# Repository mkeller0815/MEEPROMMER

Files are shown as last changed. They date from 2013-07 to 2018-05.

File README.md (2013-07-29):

MEEPROMMER
==========

(E)EPROM programmer based on Arduino hardware

The MEEPROMMER is a combination of hardware and software that lets you read and write 
data from (and to) 28Cxxx EEPROMS. Maybe later there will be enhancements to use it
also for 27Cxxx EPROMS. 

At the moment we have an working prototype on a PCB that uses an Arduino Nano and an 
Arduino-shield that can directly plugged to an Arduino Uno. 

The Arduino firmware provides a serial interface with simple commands to transfer data 
between a host computer and an eeprom.

For the host computer a Java based GUI application is available that uses the RXTX 
library to interface the programmer.

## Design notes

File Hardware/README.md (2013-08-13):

this folder contain the hardware related files

The PCB is available at: https://www.tindie.com/products/UnaClocker/28cxxx-eeprom-programmer-shield-for-arduino/

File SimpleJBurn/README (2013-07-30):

SimpleJBurn
###########

SimpleJBurn is a java application that is used to write data to an EEPROM or
read data from an EEPROM. 

The current version has the following features:

- Load an ROM image from disk (up to 32k)
- Read data from EEPROM
- Save EEPROM data to disk
- Burn image data to EEPROM 
- set an offset for burning data
- compare image data and EEPROM data
- clear EEPROM to 0x00 bytes

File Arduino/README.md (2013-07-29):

This folder contains the Arduino related files for the
firmware

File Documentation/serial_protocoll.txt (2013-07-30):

################################################################################
#
# Atmega328 based EEPROM 28C64,28C256 programmer
# serial protocol description
#
# $Date: 2013/04/12 10:55:16 $
# $Author: mario $
# $Revision: 1.4 $
#
# $Id: serial_protocoll.txt,v 1.4 2013/04/12 10:55:16 mario Exp mario $
# $Source: /Users/mario/Projekte/HomeBrew6502/Hardware/EEPROM\040Programmer/serial_protocoll.txt,v $
#  
################################################################################

Description
###########

This document describes the serial protocol that is used to talk
to the programmer. 

The programmer supports binary data as well as the Intel HEX format
version I08HEX. (support for datatype "00" and "01").
If the I08HEX dataset is page-aligned with a maximum of 64 bytes per 
row, the programmer automatically uses the fast page-write mode.

For the binary modei, page-write can be selected directly by the 
write command.

The software uses the "Data polling" mode (DB7) of the AT and ST 
models of the 28Cxxx EEPROMS to determine the end of a write cycle.

Communication
#############

The baud rate is fixed at 9600,8,N,1. This should be enough because
it provides about 1k of data to be written in one second by using 
binary write in page mode.

The programmer waits on its serial port for a command. Any command 
that is send to the programmer will be parsed and executed. At the
end a return code of 2 bytes will be send back (at least) with 
information about the success of the command execution. 

A command has to be terminated by either LF (0x0A) or CR/LF (0x0D 0x0A)
Parameters are separated by ","

Example: "bw,0f00,00ff" (command binary write at 0x0f00, 255 bytes)
         After sending the command you can check for any error code.
	 If no code is send by the programmer you can start transmitting
	 the data.

If a command was given that reads data from the EEPROM, the return 
code is send after the data has been sent. To separate the return 
code from the "data", you have to count the number of data bytes. 
This should be easy, cause for all write and read commands a 
implicit or explicit length is needed in the command parameters.

Adresses and length values are always given as hex numbers that
are always 4 byte hex values for a 16bit address 0000 to 7fff  
without the '0x' prefix. Any number bigger the 7fff will cause
an error because you should never have a address beyond 0x7fff.

Commands and parameters are always given as ASCII text, 

Commands
########

* bw	- binary write byte mode
* pw	- binary write page mode
* br	- binary read 
* hw	- intel hex write
* Hw	- intel hex write (page mode)
* hr	- intel hex read
* ??	- print help
* ve	* print version

Error codes
###########

* 00	- OK
* 01	- unknown command
* 02	- data length mismatch
* 03    - timeout waiting for data
* 04	- page align error (page write mode)
* 05    - too many bytes (page write mode)
* 06	- wrong checksum
* 07	- datatype not implemented (intel hex format)
* 08    - wrong data line format (intel hex format)
* 09	- wrong hex value in address or byte value

bw command:
-----------

  syntax:	bw,address,length

  parameter:	address :	16 bit value (0000 to 7fff) repesenting the 
				start address of the bytes to write
		length  :	16 bit value (0000 to 7fff) with number of 
				bytes to be written 

  description:	binary write "length" bytes beginning with "address". After the
		command is sent the programmer responses only in case of an 
		error with a return code. After sending the command the number 
		of databytes (binary, not as hex value) have to be send to the 
		programmer. If the number is not reached, the programmer waits 
		5 seconds after recieving the last byte until an error code is 
		returned (error 02 - data length mismatch). If too many bytes 
		are send, the programmer will stop writing the received bytes 
		to the eeprom after the "length" number of bytes are reached, 
		but the next byte that is send after that will be interpreted 
		as new command, causing either an error (01 - unknown command) 
		or unwanted behavior, because the byte is recognized as command
		If the write cycle needs some time to finish, you may have to 
		insert some breaks of about 50 ms after each 100 bytes. 
		After the bytes are successful written, the return code 
		"00" (OK) is returned, then the programmer waits for the next 
		command. 

pw command:
-----------

  syntax:	pw,address,length

  parameter:    address :       16 bit value (0000 to 7fff) repesenting the 
				start address of the bytes to write.
				the address has to be page aligned. 
				0000, 0040, 0080, 00a0, 0100, ... , etc.
                length  :       16 bit value (0000 to 0040) with number of 
				bytes to be written (maximum 64 byte)

  description:	binary write data in "page mode". This mode is much faster 
		then writing single bytes, but has some requirements. First is 
		that the address has to be page aligned. The next is that only 
		64 bytes can be written in one step. The bytes are read into 
		an internal buffer befor writing. The rest is done in the same 
		way like writing binary bytes. After the command is sent, the 
		programmer responses with a return value only in case of an 
		error. You can start sending the bytes directly after sending 
		the command string. In case of a misalignment of the address 
		the return value "04" (page align error) is returned. If the 
		length parameter is bigger then 0x0040 (64 bytes) the error 
		"05" (too many bytes) is returned. In case of any error, do 
		not start sending databytes, as they are interpreted as new 
		command, causing errors or unwanted behavior.  

br command:
-----------

  syntax:	br,address,length

  parameter:    address :       16 bit value (0000 to 7fff) repesenting the 
				start address of the bytes to read
                length  :       16 bit value (0000 to 7fff) with number of 
				bytes to be read

  description:	binary read data, beginning at the given address. The "length" 
		number of bytes are read from the eeprom and send to the serial
		connection as single byte values (not hex values). After the 
		"length" number of bytes are sent, the additional return value 
		"00" (OK) is sent. Be aware that these two byte do not belong 
		to the data from the eeprom, so take care for the number of 
		bytes that you expect from the read command.  

hw command:	
-----------

  syntax:	hw

  parameter:	none

  description:	start intel hex format write. The current firmware only supports
		I09HEX format, implementing the "00" data record and the "01" 
		end of file record types. the maximum number of bytes per data 
		line is 256 (third field in record line 0x00 to 0xff ). The 
		line has to end with either LF or CR/LF. A complete line is read
		into an internal buffer and then is parsed and written to the 
		EEPROM. If the address is page aligned an there are not more 
		then 64 bytes in the line the programmer automatically uses the
		faster page write mode.  If the checksum is not correct, an 
		error is returned (06) and the data line will not be written.
		Errors are also returned if 
		* a wrong record type is used (07)
		* the format of the dataline is not correct (08)
		* mistyped hex values are found in the line (09)
		* the line is not completed and a timeout occures (03)
		After the line is written, the return value "00" is send to 
		indicate that the next line can be written. The last line to 
		send is a "01" record line (end of file record) to end the hex 
		write mode.

hr command:
-----------

  syntax:	hr,address,length,bbl

  parameter:    address :       16 bit value (0000 to 7fff) repesenting the 
				start address of the bytes to read
                length  :       16 bit value (0000 to 7fff) with number of 
				bytes to be read
		bbl	:	8 bit value (00 to ff) with the number 
				of bytes per line

  description:  this mode works like the binary read mode, except, that the 
		data is transmitted as intel hex format. Each line contains 
		the number of data bytes specified in the "bbl" parameter 
		(max. 255) also the checksum is provided at the end of the line.
		Lines are separated by "LF" the last line that is send is a "01"
		(end of file record) that indicated the end of the data 
		transmission. After the last line is send, the "00" return value
		is returned showing that the next command can be executed.  

?? command:
-----------

  syntax:	??

  parameter:	none

  description:	prints out the help text to the serial connection

ve command:
-----------

  syntax:	ve

  parameter:	none

  description:	prints out the version information of the current firmware
		The version string contains a version number as well as the 
		commands that are supported at the moment:
		like:  "MEEPROMER V0.91 2013-04-13; CMD:bw,br,pw,ve,??"

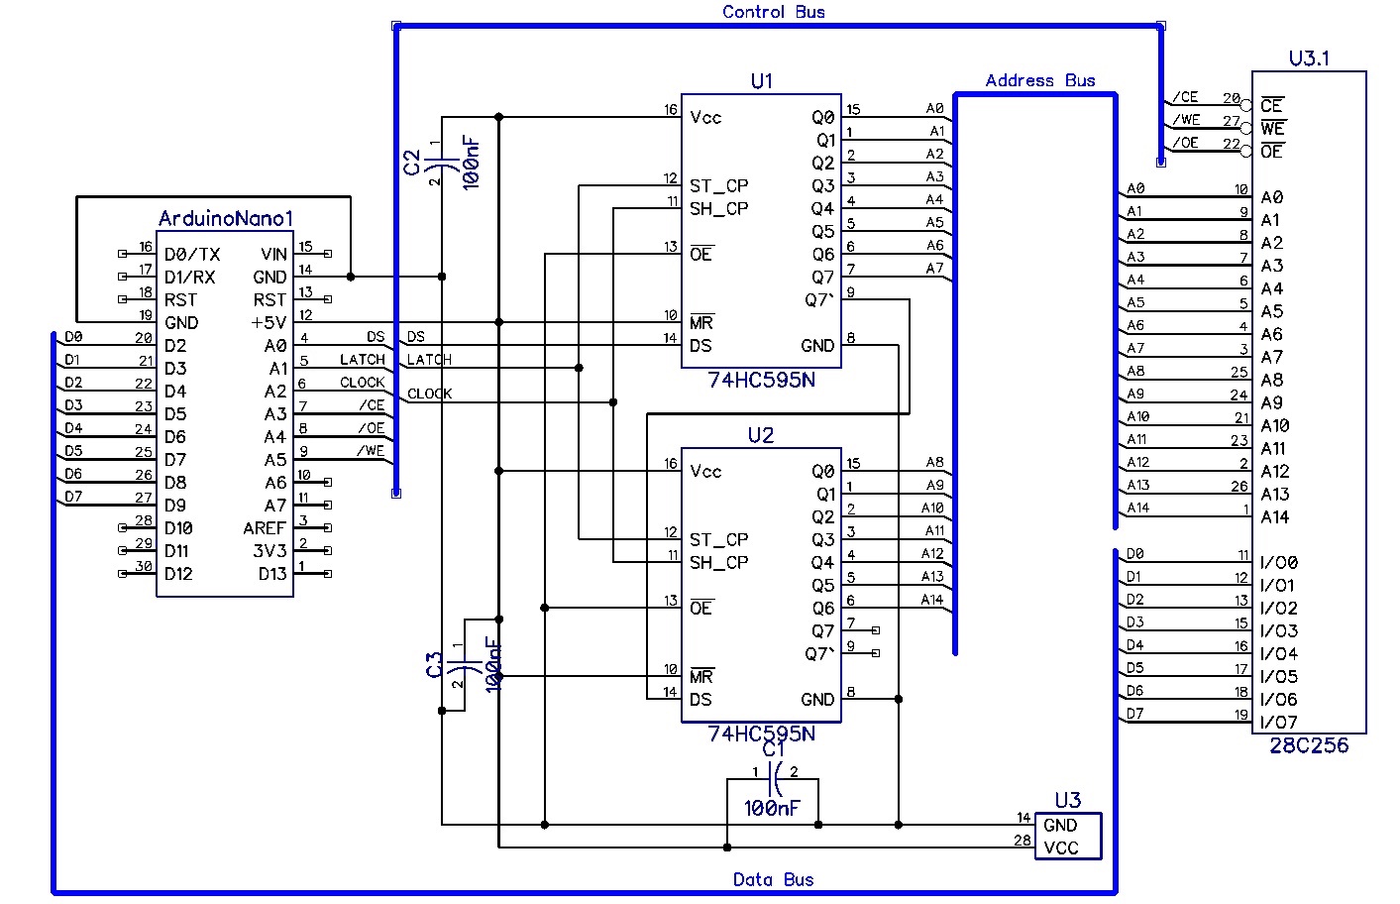
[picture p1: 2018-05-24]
Hardware/Prototype_schema.jpg

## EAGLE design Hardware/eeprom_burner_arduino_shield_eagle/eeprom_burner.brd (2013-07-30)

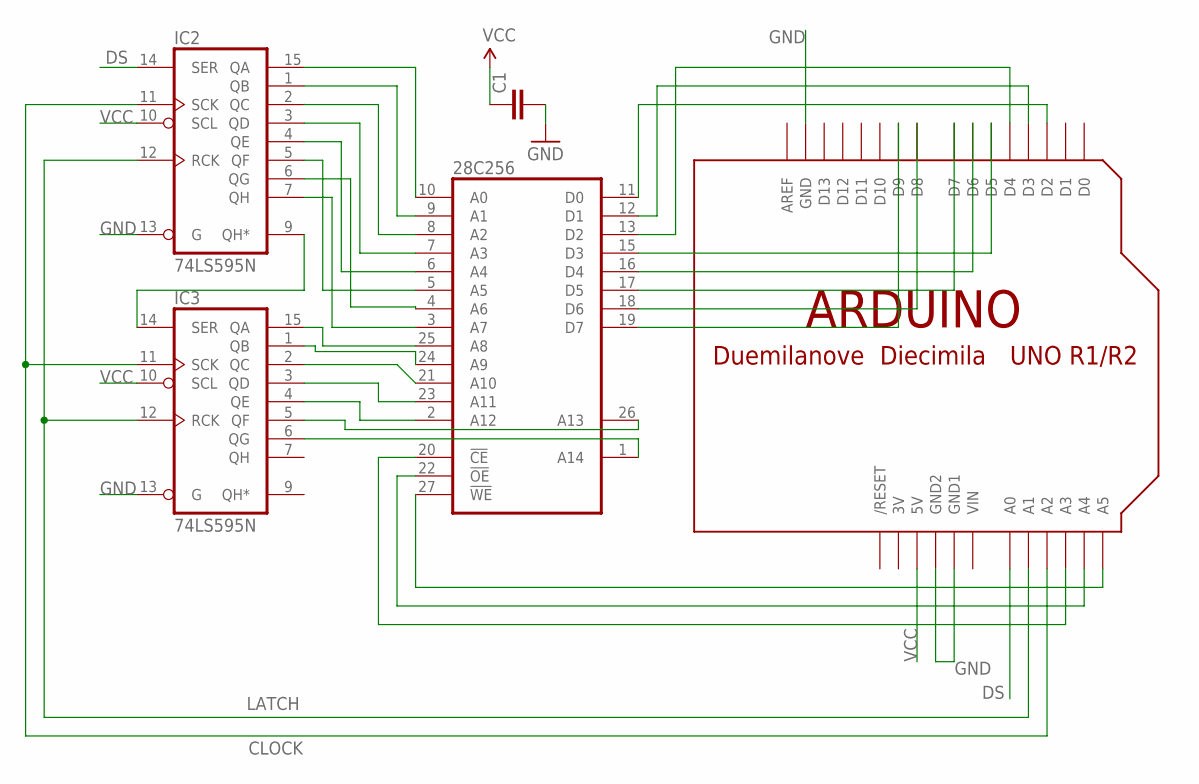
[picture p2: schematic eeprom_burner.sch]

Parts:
28C256: 2864; DIL28
C1: CAPPTH; CAP-PTH-SMALL
IC2, IC3: 74LS595N; DIL16
U$1: ARDUINOUNO; ARDUINO

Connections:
3V: U$1.3V
CLOCK: IC2.11 (SCK), IC3.11 (SCK), U$1.A2
DS: IC2.14 (SER), U$1.A0
GND: 28C256.14 (GND), C1.2, IC2.8 (GND), IC2.13 (G), IC3.8 (GND), IC3.13 (G), U$1.GND, U$1.GND1, U$1.GND2
LATCH: IC2.12 (RCK), IC3.12 (RCK), U$1.A1
unnamed: 28C256.27 (!WE), U$1.A5
unnamed: 28C256.22 (!OE), U$1.A4
unnamed: 28C256.20 (!CE), U$1.A3
unnamed: 28C256.11 (D0), U$1.D2
unnamed: 28C256.12 (D1), U$1.D3
unnamed: 28C256.13 (D2), U$1.D4
unnamed: 28C256.15 (D3), U$1.D5
unnamed: 28C256.16 (D4), U$1.D6
unnamed: 28C256.17 (D5), U$1.D7
unnamed: 28C256.18 (D6), U$1.D8
unnamed: 28C256.19 (D7), U$1.D9
unnamed: 28C256.10 (A0), IC2.15 (QA)
unnamed: 28C256.9 (A1), IC2.1 (QB)
unnamed: 28C256.8 (A2), IC2.2 (QC)
unnamed: 28C256.7 (A3), IC2.3 (QD)
unnamed: 28C256.6 (A4), IC2.4 (QE)
unnamed: 28C256.5 (A5), IC2.5 (QF)
unnamed: 28C256.4 (A6), IC2.6 (QG)
unnamed: 28C256.3 (A7), IC2.7 (QH)
unnamed: IC2.9 (QH*), IC3.14 (SER)
unnamed: 28C256.25 (A8), IC3.15 (QA)
unnamed: 28C256.24 (A9), IC3.1 (QB)
unnamed: 28C256.21 (A10), IC3.2 (QC)
unnamed: 28C256.23 (A11), IC3.3 (QD)
unnamed: 28C256.2 (A12), IC3.4 (QE)
unnamed: 28C256.26 (A13), IC3.5 (QF)
unnamed: 28C256.1 (A14), IC3.6 (QG)
VCC: 28C256.28 (VCC), C1.1, IC2.10 (SCL), IC2.16 (VCC), IC3.10 (SCL), IC3.16 (VCC), U$1.5V
VIN: U$1.VIN

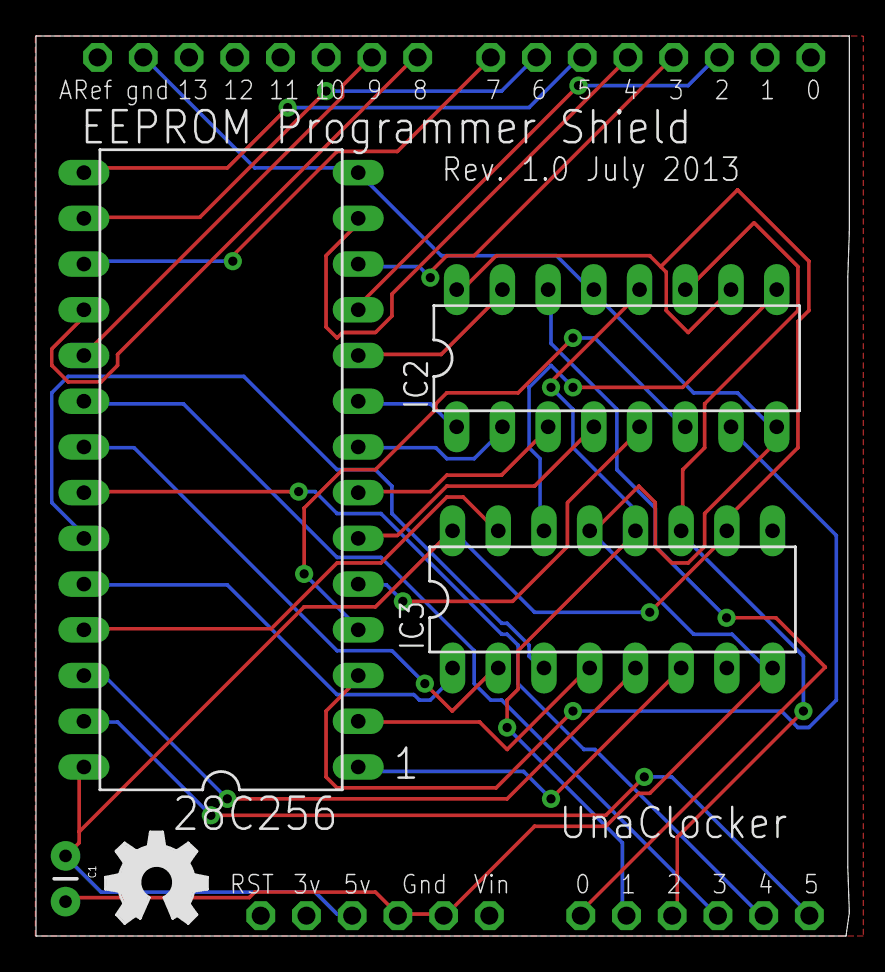
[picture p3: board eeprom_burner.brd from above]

Board: 2 copper layers, 45.2 x 50.0 mm, 7 parts (1 on the bottom side), 32 nets.

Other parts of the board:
U$2, U$3: OSHW_FILLX200_NOTEXT

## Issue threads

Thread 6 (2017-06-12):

Zero bits cleared in uncontrolled manner. Latent problem in write_data_bus() on AT28C256

kervinck, 2017-06-12:
```
//write a byte to the data bus
//be sure to set data_bus to output before
void write_data_bus(byte data)
{
  //2 bits belong to PORTB and have to be set separtely
  digitalWrite(D6, (data >> 6) & 0x01);
  digitalWrite(D7, (data >> 7) & 0x01);
  //bit 0 to 6 belong to bit 2 to 8 of PORTD
  PORTD = PIND | ( data << 2 ); // <--- this statement works by accident? (MvK)
  ^^^^^^^^^^^^^^^^^^^^^^^^^^^^^
}
```

I have the impression that the only reason that this statement works is because the bus is put into high-impedance mode for quite a while before every byte write, and apparently that resets all bus bits to 0. In that case "PIND | (data << 2)" sets the correct data.

However, in high-speed operation this is not the case, and earlier 1's get stuck. I found this because I extended the MEEPrommer to lock/unlock AT28c256 chips. They require specific lock/unlock sequences to be sent at a higher speed.

I suggest to rewrite the body along these lines:
```
  PORTB = (PINB & B11111100) | (data >> 6);
  PORTD = (PIND & B00000011) | (data << 2);
```
Note the explicit clearing of the old bits prior to OR'ing the new data.

I spent several days with a scope debugging this, fiddling with timings, different voltages, pulldown and pullup resistors until I spotted this. With the above proposal, the lock/unlock sequences work for me...

retux, 2018-08-29:
Hey Kervinck,
I'm having probably the same issue. So far my best bet is that it might be due to timing problem. Do you suggest to replace the line

 PORTD = PIND | ( data << 2 ); //

By the ones you mentioned? Could I get your code with the unlock sequence?
Thanks!

kervinck, 2018-08-29:
Here is my version. It is heavily modified in an attempt to understand the code and add features, so that is why I didn't consider a pull request. But you can see the above-mentioned fragment in it, and the unlock routine is there as well. While it worked and I'm pretty sure his version is the last I used, I don't use this code anymore today. "For reference only"
[MEEPROMMERfirmware-kervinck.ino.zip](https://github.com/mkeller0815/MEEPROMMER/files/2332331/MEEPROMMERfirmware-kervinck.ino.zip)

retux, 2018-08-29:
Thanks a lot! I will try to analyze and compare the code to see if i can get it to work.

retux, 2018-09-03:
Hey kervinck, thanks to your version I was able move a bit further. Still there is a way to go, but i believe I'm closer. If i read from eeprom (at28c256) I get every byte 0xFF, but when I try to write there must be something wrong with data polling as program remains in the loop:

MEEPROMMER-MvK (derived from MEEPROMMER 1.2), CMD:R,r,w,W,V,v
0000: FF FF FF FF FF FF FF FF FF FF FF FF FF FF FF FF
0010: FF
%
writeBlock address 0x0000 bytes 0x1
error address 0x0000 expected 0x61 actual 0xFF writeTime 110.89
info retry 1
error address 0x0000 expected 0x61 actual 0xFF writeTime 179.42
info retry 2

I also tried with a sram I had (6264). With it I can write byte by byte through arduino serial monitor, and that works, but when I try to write 8kb from a binary file the data in ram does not match.

kervinck, 2018-09-03:
I haven't looked at the code for more than a year. There remained too much experimenting involved with getting the sequences right for each chip. In the end I bought a cheap programmer (MiniPro TL866 like) on aliexpress and never looked back.

khelifk, 2023-12-23:
> Here is my version. It is heavily modified in an attempt to understand the code and add features, so that is why I didn't consider a pull request. But you can see the above-mentioned fragment in it, and the unlock routine is there as well. While it worked and I'm pretty sure his version is the last I used, I don't use this code anymore today. "For reference only" [MEEPROMMERfirmware-kervinck.ino.zip](https://github.com/mkeller0815/MEEPROMMER/files/2332331/MEEPROMMERfirmware-kervinck.ino.zip)
Hi all,
Thank you Kervinck, I was strugling with the code, and seems your program is working like a charm, thank you

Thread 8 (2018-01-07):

Exception in thread "main" java.lang.NoClassDefFoundError: gnu/io/CommPortIdentifier

aj22r, 2018-01-07:
I have RXTXcomm.jar in C:\Program Files (x86)\Java\jdk1.8.0_131\jre\lib\ext and rxtxSerial.dll in C:\Program Files (x86)\Java\jdk1.8.0_131\jre\bin but it still gives me the error

mkeller0815, 2018-01-08:
Please follow the installation instructions in http://rxtx.qbang.org/wiki/index.php/Installation_for_Windows
Also check that the SimpleJBurn is executed by the java version you have the rxtx lib installed for.
Hope that helps.

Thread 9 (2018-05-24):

Prototype_schema.jpg Error?

creoguy, 2018-05-24:
The pin labels for the Arduino Nano appear to be incorrect for A0-A7. On the schematic, it shows A0 as pin 11 and A7 as pin 4. Pin 4 should be A0 and Pin 11 should be A7 with A1-A6 swapped in-between as well.

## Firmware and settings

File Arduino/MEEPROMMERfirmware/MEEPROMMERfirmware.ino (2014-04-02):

/**
 * ** project Arduino EEPROM programmer **
 * 
 * This sketch can be used to read and write data to a
 * AT28C64 or AT28C256 parallel EEPROM
 *
 * $Author: mario $
 * $Date: 2013/05/05 11:01:54 $
 * $Revision: 1.2 $
 *
 * This software is freeware and can be modified, reused or thrown away without any restrictions.
 *
 * Use this code at your own risk. I'm not responsible for any bad effect or damages caused by this software!!!
 *
 **/

#define VERSIONSTRING "MEEPROMMER $Revision: 1.2 $ $Date: 2013/05/05 11:01:54 $, CMD:R,r,w,W,V"

// shiftOut part
#define DS      A0
#define LATCH   A1
#define CLOCK   A2

#define PORTC_DS      0
#define PORTC_LATCH   1
#define PORTC_CLOCK   2


// eeprom stuff
// define the IO lines for the data - bus
#define D0 2
#define D1 3
#define D2 4
#define D3 5
#define D4 6
#define D5 7
#define D6 8
#define D7 9

// define the IO lines for the eeprom control
#define CE A3
#define OE A4
#define WE A5
#define PORTC_CE   3
#define PORTC_OE   4
#define PORTC_WE   5

//a buffer for bytes to burn
#define BUFFERSIZE 1024 
byte buffer[BUFFERSIZE];
//command buffer for parsing commands
#define COMMANDSIZE 32
char cmdbuf[COMMANDSIZE];

unsigned int startAddress,endAddress;
unsigned int lineLength,dataLength;

//define COMMANDS
#define NOCOMMAND    0
#define VERSION      1
#define SET_ADDRESS  2

#define READ_HEX    10
#define READ_BIN    11
#define READ_ITL    12

#define WRITE_HEX   20
#define WRITE_BIN   21
#define WRITE_ITL   22


/*****************************************************************
 *
 *  CONTROL and DATA functions
 *
 ****************************************************************/

// switch IO lines of databus to INPUT state
void	    data_bus_input() {
  pinMode(D0, INPUT);
  pinMode(D1, INPUT);
  pinMode(D2, INPUT);
  pinMode(D3, INPUT);
  pinMode(D4, INPUT);
  pinMode(D5, INPUT);
  pinMode(D6, INPUT);
  pinMode(D7, INPUT);
}

//switch IO lines of databus to OUTPUT state
void data_bus_output() {
  pinMode(D0, OUTPUT);
  pinMode(D1, OUTPUT);
  pinMode(D2, OUTPUT);
  pinMode(D3, OUTPUT);
  pinMode(D4, OUTPUT);
  pinMode(D5, OUTPUT);
  pinMode(D6, OUTPUT);
  pinMode(D7, OUTPUT);
}

//set databus to input and read a complete byte from the bus
//be sure to set data_bus to input before
byte read_data_bus()
{
  return ((digitalRead(D7) << 7) +
    (digitalRead(D6) << 6) +
    (digitalRead(D5) << 5) +
    (digitalRead(D4) << 4) +
    (digitalRead(D3) << 3) +
    (digitalRead(D2) << 2) +
    (digitalRead(D1) << 1) +
    digitalRead(D0));

}


//write a byte to the data bus
//be sure to set data_bus to output before
void write_data_bus(byte data)
{
  //2 bits belong to PORTB and have to be set separtely 
  digitalWrite(D6, (data >> 6) & 0x01);
  digitalWrite(D7, (data >> 7) & 0x01);
  //bit 0 to 6 belong to bit 2 to 8 of PORTD
  PORTD = PIND | ( data << 2 );
}

//shift out the given address to the 74hc595 registers
void set_address_bus(unsigned int address)
{

  //get high - byte of 16 bit address
  byte hi = address >> 8;
  //get low - byte of 16 bit address
  byte low = address & 0xff;

  //disable latch line
  bitClear(PORTC,PORTC_LATCH);

  //shift out highbyte
  fastShiftOut(hi);
  //shift out lowbyte
  fastShiftOut(low);

  //enable latch and set address
  bitSet(PORTC,PORTC_LATCH);

}

//faster shiftOut function then normal IDE function (about 4 times)
void fastShiftOut(byte data) {
  //clear data pin
  bitClear(PORTC,PORTC_DS);
  //Send each bit of the myDataOut byte MSBFIRST
  for (int i=7; i>=0; i--)  {
    bitClear(PORTC,PORTC_CLOCK);
    //--- Turn data on or off based on value of bit
    if ( bitRead(data,i) == 1) {
      bitSet(PORTC,PORTC_DS);
    }
    else {      
      bitClear(PORTC,PORTC_DS);
    }
    //register shifts bits on upstroke of clock pin  
    bitSet(PORTC,PORTC_CLOCK);
    //zero the data pin after shift to prevent bleed through
    bitClear(PORTC,PORTC_DS);
  }
  //stop shifting
  bitClear(PORTC,PORTC_CLOCK);
}

//short function to set the OE(output enable line of the eeprom)
// attention, this line is LOW - active
void set_oe (byte state)
{
  digitalWrite(OE, state);
}

//short function to set the CE(chip enable line of the eeprom)
// attention, this line is LOW - active
void set_ce (byte state)
{
  digitalWrite(CE, state);
}

//short function to set the WE(write enable line of the eeprom)
// attention, this line is LOW - active
void set_we (byte state)
{
  digitalWrite(WE, state);
}

//highlevel function to read a byte from a given address
byte read_byte(unsigned int address)
{
  byte	    data = 0;
  //set databus for reading
  data_bus_input();
  //first disbale output
  set_oe(HIGH);
  //enable chip select
  set_ce(LOW);
  //disable write
  set_we(HIGH);
  //set address bus
  set_address_bus(address);
  //enable output
  set_oe(LOW);
  data = read_data_bus();

  //disable output
  set_oe(HIGH);

  return data;

}


//highlevel function to write a byte to a given address
//this function uses /DATA polling to get the end of the
//write cycle. This is much faster then waiting 10ms
void fast_write(unsigned int address, byte data)
{
  byte cyclecount=0;

  //first disbale output
  set_oe(HIGH);

  //disable write
  set_we(HIGH);

  //set address bus
  set_address_bus(address);

  //set databus to output
  data_bus_output();

  //set data bus
  write_data_bus(data);

  //enable chip select
  set_ce(LOW);

  //wait some time to finish writing
  delayMicroseconds(1);

  //enable write
  set_we(LOW);

  //wait some time to finish writing
  delayMicroseconds(1);

  //disable write
  set_we(HIGH);

  data_bus_input();

  set_oe(LOW);

  while(data != read_data_bus()) {
    cyclecount++;
  };

  set_oe(HIGH);
  set_ce(HIGH);

}



/************************************************
 *
 * COMMAND and PARSING functions
 *
 *************************************************/

//waits for a string submitted via serial connection
//returns only if linebreak is sent or the buffer is filled
void readCommand() {
  //first clear command buffer
  for(int i=0; i< COMMANDSIZE;i++) cmdbuf[i] = 0;
  //initialize variables
  char c = ' ';
  int idx = 0;
  //now read serial data until linebreak or buffer is full
  do {
    if(Serial.available()) {
      c = Serial.read();
      cmdbuf[idx++] = c;
    }
  } 
  while (c != '\n' && idx < (COMMANDSIZE)); //save the last '\0' for string end
  //change last newline to '\0' termination
  cmdbuf[idx - 1] = 0;
}

//parse the given command by separating command character and parameters
//at the moment only 5 commands are supported
byte parseCommand() {
  //set ',' to '\0' terminator (command string has a fixed strucure)
  //first string is the command character
  cmdbuf[1]  = 0;
  //second string is startaddress (4 bytes)
  cmdbuf[6]  = 0;
  //third string is endaddress (4 bytes)
  cmdbuf[11] = 0;
  //fourth string is length (2 bytes)
  cmdbuf[14] = 0;
  startAddress=hexWord((cmdbuf+2));
  dataLength=hexWord((cmdbuf+7));
  lineLength=hexByte(cmdbuf+12);
  byte retval = 0;
  switch(cmdbuf[0]) {
  case 'A':
    retval = SET_ADDRESS;
    break;
  case 'R':
    retval = READ_HEX;
    break;
  case 'r':
    retval = READ_BIN;
    break;
  case 'W':
    retval = WRITE_HEX;
    break;
  case 'w': 
    retval = WRITE_BIN;
    break;
  case 'V':
    retval = VERSION; 
    break;
  default:
    retval = NOCOMMAND;
    break;
  }

  return retval;
}

/************************************************************
 * convert a single hex digit (0-9,a-f) to byte
 * @param char c single character (digit)
 * @return byte represented by the digit 
 ************************************************************/
byte hexDigit(char c)
{
  if (c >= '0' && c <= '9') {
    return c - '0';
  } 
  else if (c >= 'a' && c <= 'f') {
    return c - 'a' + 10;
  } 
  else if (c >= 'A' && c <= 'F') {
    return c - 'A' + 10;
  } 
  else {
    return 0;   // getting here is bad: it means the character was invalid
  }
}

/************************************************************
 * convert a hex byte (00 - ff) to byte
 * @param c-string with the hex value of the byte
 * @return byte represented by the digits 
 ************************************************************/
byte hexByte(char* a)
{
  return ((hexDigit(a[0])*16) + hexDigit(a[1]));
}

/************************************************************
 * convert a hex word (0000 - ffff) to unsigned int
 * @param c-string with the hex value of the word
 * @return unsigned int represented by the digits 
 ************************************************************/
unsigned int hexWord(char* data) {
  return ((hexDigit(data[0])*4096)+
    (hexDigit(data[1])*256)+
    (hexDigit(data[2])*16)+
    (hexDigit(data[3]))); 
}


/************************************************
 *
 * INPUT / OUTPUT Functions
 *
 *************************************************/


/**
 * read a data block from eeprom and write out a hex dump 
 * of the data to serial connection
 * @param from       start address to read fromm
 * @param to         last address to read from
 * @param linelength how many hex values are written in one line
 **/
void read_block(unsigned int from, unsigned int to, int linelength)
{
  //count the number fo values that are already printed out on the
  //current line
  int		    outcount = 0;
  //loop from "from address" to "to address" (included)
  for (unsigned int address = from; address <= to; address++) {
    if (outcount == 0) {
      //print out the address at the beginning of the line
      Serial.println();
      Serial.print("0x");
      printAddress(address);
      Serial.print(" : ");
    }
    //print data, separated by a space
    byte data = read_byte(address);
    printByte(data);
    Serial.print(" ");
    outcount = (++outcount % linelength);

  }
  //print a newline after the last data line
  Serial.println();

}

/**
 * read a data block from eeprom and write out the binary data 
 * to the serial connection
 * @param from       start address to read fromm
 * @param to         last address to read from
 **/
void read_binblock(unsigned int from, unsigned int to) {
  for (unsigned int address = from; address <= to; address++) {
    Serial.write(read_byte(address));
  }
  //print out an additional 0-byte as success return code
  Serial.print('\0');
  
}  
  
/**
 * write a data block to the eeprom
 * @param address  startaddress to write on eeprom
 * @param buffer   data buffer to get the data from
 * @param len      number of bytes to be written
 **/
void write_block(unsigned int address, byte* buffer, int len) {
  for (unsigned int i = 0; i < len; i++) {
    fast_write(address+i,buffer[i]);
  }   
}


/**
 * print out a 16 bit word as 4 character hex value
 **/
void printAddress(unsigned int address) {
  if(address < 0x0010) Serial.print("0");
  if(address < 0x0100) Serial.print("0");
  if(address < 0x1000) Serial.print("0");
  Serial.print(address, HEX);

}

/**
 * print out a byte as 2 character hex value
 **/
void printByte(byte data) {
  if(data < 0x10) Serial.print("0");
  Serial.print(data, HEX);  
}





/************************************************
 *
 * MAIN
 *
 *************************************************/
void setup() {
  //define the shiuftOut Pins as output
  pinMode(DS, OUTPUT);
  pinMode(LATCH, OUTPUT);
  pinMode(CLOCK, OUTPUT);

  //define the EEPROM Pins as output
  // take care that they are HIGH
  digitalWrite(OE, HIGH);
  pinMode(OE, OUTPUT);
  digitalWrite(CE, HIGH);
  pinMode(CE, OUTPUT);
  digitalWrite(WE, HIGH);
  pinMode(WE, OUTPUT);

  //set speed of serial connection
  //Serial.begin(57600);
  Serial.begin(115200);
}

/**
 * main loop, that runs invinite times, parsing a given command and 
 * executing the given read or write requestes.
 **/
void loop() {
  readCommand();
  byte cmd = parseCommand();
  int bytes = 0;
  switch(cmd) {
  case SET_ADDRESS:
    // Set the address bus to an arbitrary value.
    // Useful for debugging shift-register wiring, byte-order.
    // e.g. A,00FF
    Serial.print("Setting address bus to 0x");
    Serial.println(cmdbuf + 2);
    set_address_bus(startAddress);
    break;
  case READ_HEX:
    //set a default if needed to prevent infinite loop
    if(lineLength==0) lineLength=32;
    endAddress = startAddress + dataLength -1;
    read_block(startAddress,endAddress,lineLength);
    Serial.println('%');
    break;
  case READ_BIN:
    endAddress = startAddress + dataLength -1;
    read_binblock(startAddress,endAddress);
    break;
  case READ_ITL:
    break;
  case WRITE_BIN:
    //take care for max buffer size
    if(dataLength > 1024) dataLength = 1024;
    endAddress = startAddress + dataLength -1;
    while(bytes < dataLength) {
      if(Serial.available()) buffer[bytes++] = Serial.read();
    }    
    write_block(startAddress,buffer,dataLength);
    Serial.println('%');
    
    break;
  case WRITE_HEX:
    break;
  case WRITE_ITL:
    break;
  case VERSION:
    Serial.println(VERSIONSTRING);
    break;
  default:
    break;    
  }


}

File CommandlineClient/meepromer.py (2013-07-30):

#!/usr/bin/env python
# vim:fileencoding=ISO-8859-1
# 
# MEEPROMER - Mario's EEPROMer Python script
# Scot W. Stevenson <scot.stevenson@gmail.com>
# Version 0.1 ALPHA  11. April 2013
#
# TODO dislamer
# TODO license
# 
# Requires Python 2.7 or later; will not work with Python 3.0 or later
#
# TODO expand doc string below

"""Simple command line tool for connecting to the meeprom EEPROMer.

Packages required that are not part of the Python Standard Library:
    PySerial
"""

# Package imports. PySerial is only imported if needed (see below)

import argparse 
import sys

# Constants

BAUDRATE = 9600
PROTOCOL_VERSION = None         # TODO add protocol version for checks
SERIAL_PORT = '/dev/cu.usbserial-FTAKHP5D'
SERIAL_TIMEOUT = 1              # in seconds


# ----------------------------------------------------------------------
# Parse command line arguments

parser = argparse.ArgumentParser(
        description='Meepromer Command Line Interface',
        epilog='Read source for further information')

task = parser.add_mutually_exclusive_group()
task.add_argument('-w', '--write', dest="cmd", action="store_const",
        const="write", help='Write to EEPROM')
task.add_argument('-r', '--read', dest="cmd", action="store_const",
        const="read", help='Read from EEPROM (binary)')
task.add_argument('-d', '--dump', dest="cmd", action="store_const",
        const="dump", help='Read from EEPROM (ascii)')
task.add_argument('-D', '--diff', dest="cmd", action="store_const",
        const="diff", help='Write bytes that differ')
task.add_argument('-v', '--verify', dest="cmd", action="store_const",
        const="verify", help='Compare EEPROM with file')

parser.add_argument('-a', '--address', nargs=1, action='store',
        default='0000', help='Starting address (as hex), default 0000')
parser.add_argument('-b', '--bytes', nargs=1, action='store',
        default='1', help='Number of bytes to read or write, default 1')
parser.add_argument('-f', '--file', nargs=1, help='Name of data file',
        action='store', type=file)
parser.add_argument('-i', '--info', action="store_true",
        help='Display status of EEPROMer and quit')
parser.add_argument('-s', '--serial', nargs=1, action='store', 
        help='Serial port address')
parser.add_argument('-V', '--version', action='version',
        version='%(prog)s ALPHA 0.1')

args = parser.parse_args()


# Quit ALPHA version cleanly
# TODO replace 

sys.exit(0)

# ----------------------------------------------------------------------
# Setup serial port

def _setup_serial():
    """Set up the serial port. Currently only tested on Mac OS X 10.8"""

    try:
        import serial
    except ImportError:
        print "Program requires the PySerial module. Install with"
        print "    sudo easy_install PySerial [for Mac and Linux]"
        print "and try again."
        sys.exit(1)

    ser = serial.Serial(SERIAL_PORT, BAUDRATE, timeout=1)

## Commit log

2013-07-29 Replaced output to log window with a generic function in all methods of MainFrame.java
    [MainFrame.java]
2013-07-30 added additional files
    [eeprom_burner.brd, eeprom_burner.sch]
2013-08-13 adjustes serial speed to 115200 and added link to PCB on tindie.com
2013-11-22 CMD list in version string corrected; matches parseCommand().
    `parseCommand()` defines commands as:
    ```
    R: READ_HEX
    r: READ_BIN
    W: WRITE_HEX
    w: WRITE_BIN
    V: VERSION
    ```
    This patch fixes the command list advertised in the version string to match that list; `R,r,w,W,V`
    [MEEPROMMERfirmware.ino]
2013-11-22 New 'A,0000' command sets address bus to given value.
    Useful for debugging shift-register wiring and the resulting address bus
    byte order.
    e.g. `A,00FF` should only set A0..A7 high.
2013-11-22 Shift high byte of address bus first.
    The schematic at http://www.ichbinzustaendig.de/dev/meeprommer-en shows
    the low-byte address bus 74HC595 (EEPROM A0..A7) connected first,
    cascading into the high-byte 74HC595. This means the high byte should be
    shifted first. The code comments reflect this, but the actual code
    doesn't.
    Note that @presslab-us's fork shifts the high byte first, although he
    says he didn't specifically change the address byte order. I'm not sure
    how it crept in here - probably while experimenting for a board with
    the '595 chips wired in reverse.
    [MEEPROMMERfirmware.ino]
2018-05-24 fixed pinout of Arduino nano in prototype_schema.jpg

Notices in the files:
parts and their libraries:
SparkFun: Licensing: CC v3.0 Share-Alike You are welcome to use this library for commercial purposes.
